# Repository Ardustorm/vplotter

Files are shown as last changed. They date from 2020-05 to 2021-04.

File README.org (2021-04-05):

* Intro
This project is a work in progress, but the goal is to make a hanging vplotter robot that is completely self contained and is controlled by the esp32. It uses 2 DC motors with encoders instead of the usual stepper motors.

I'm currently in the process of starting over again, this time using the Arduino framework since my goal is to make something that is easy for other people to use. (You can still checkout the previous version on its own branch.) Currently, I have remade a web debug interface using websockets that makes it easy to view, graph, and modify variables from a browser. I also was able to figure out how to read the encoders and update the motors from an ISR, and I'll be working on adding documentation about that shortly on hackaday.io. Eventually, I plan on splitting these parts of the code out into their own libraries since I think they could be useful for other people.

* Websockets debug
  https://hackaday.io/project/164975-portable-vertical-plotter/log/191201-websockets-debug

* This is built standing on the shoulders of these projects:
  - https://github.com/me-no-dev/AsyncTCP (esp32 webserver base)
  - https://github.com/me-no-dev/ESPAsyncWebServer (esp32 webserver with websockets)
  - https://picnicss.com/ (css styling for webpage)
  - https://github.com/leeoniya/uPlot/ (js plotting library)

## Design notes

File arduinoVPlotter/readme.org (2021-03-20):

* Overview
  - Right now I modified the sample script to be a simple websockets messaging app
  - I ran into a lot of issues, but the problem was me. I wasn't converting a 'String' into a char array which lead to a lot of issues.

* Notes:
  - Installed via zip:
    - https://github.com/me-no-dev/AsyncTCP
    - https://github.com/me-no-dev/ESPAsyncWebServer
  - Installed this to upload SPIFFS data:
    - https://github.com/me-no-dev/arduino-esp32fs-plugin
  - To use the built in js Ace editor navigate to url/edit

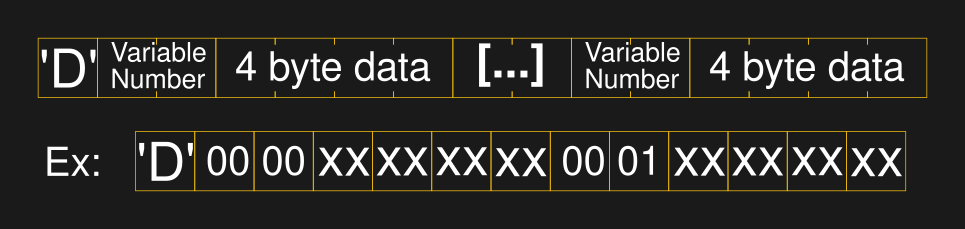
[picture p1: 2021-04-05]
documentation/websocketPackets_data.png

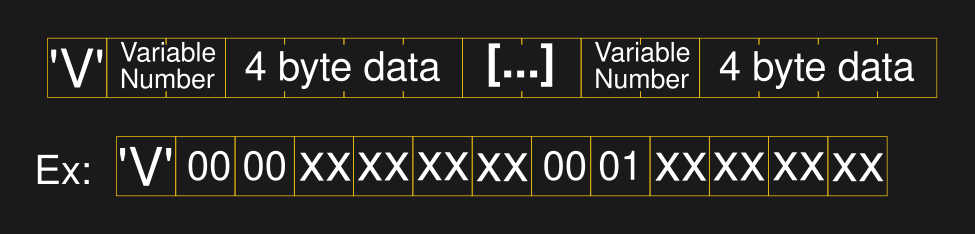
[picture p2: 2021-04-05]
documentation/websocketPackets_variable.png

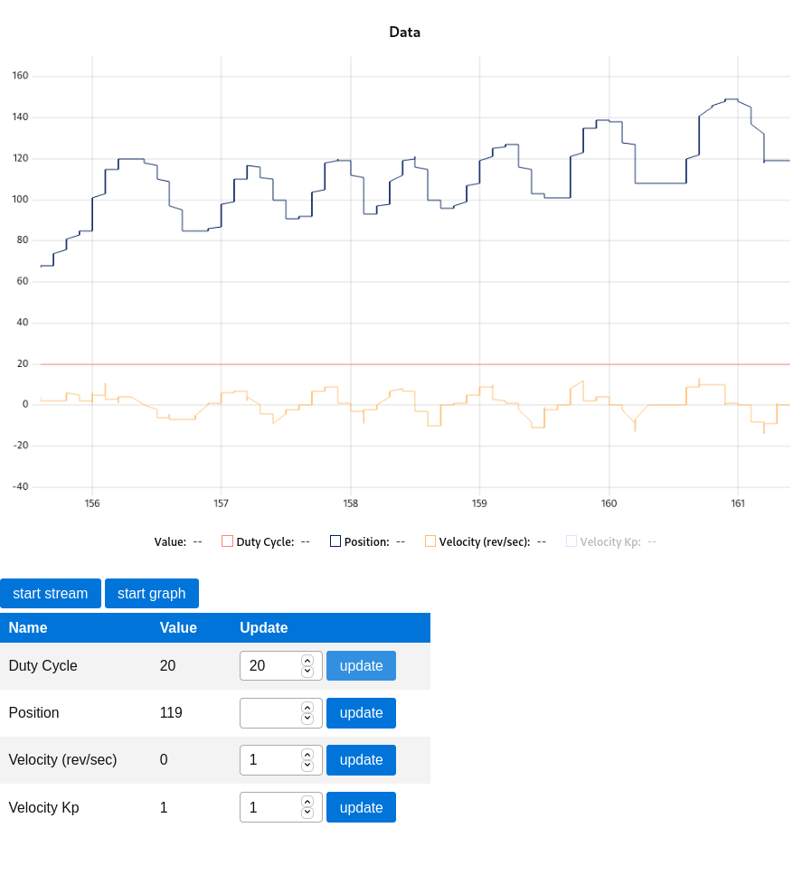
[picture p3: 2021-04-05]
documentation/websocketData_Screenshot.png

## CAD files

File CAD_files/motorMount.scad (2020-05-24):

$fn=100;
e=0.001;

dist = 70;

union(){
   translate([dist/2,0,0])
      motor();
   translate([-dist/2,0,0])
      motor();
   translate([0,0,1])
   cube([dist-10.5,15,2],center=true);
}



module motor(){
   wall = 1.5;
   depth = 10;
   translate([0,0,depth/2+wall/2])
   difference(){
      cube([10,12,depth]+[2*wall,2*wall,wall],center=true);
      translate([0,0,wall/2+e])
	 cube([10.25,12.25,depth],center=true);
      cylinder(d=4.5, h=4*depth, center=true);
   }
}

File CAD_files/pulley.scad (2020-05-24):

$fn=200;

diameter = 50;
lip_dia = 5;
lip_thick = 2;
width = 9;

pulley();

/* difference(){ */
/*    cylinder(d=15,h=5); */
/*    shaft(); */
/*    /\* lead-in's *\/ */
/*    translate([0,0,-0.1]) */
/*       cylinder(d1=4, d2=3,h=1.1); */

/*    } */

module pulley(){
   difference(){
      union(){
	 difference(){
	    union(){
	       cylinder(d=diameter, h=width);
	       cylinder(d=diameter+2*lip_dia, h=lip_thick);
	    }

	    cutouts();

	    /* lead-in's */
	    translate([0,0,width-1])
	       cylinder(d1=3, d2=4,h=1.1);
	    translate([0,0,-0.1])
	       cylinder(d1=4, d2=3,h=1.1);

	    /* Hole for thread */
	    translate([0,-diameter/3,width/2])rotate([90,0,0])
	       cylinder(r=.75,h=diameter);

	 }
	 cylinder(d=diameter/4, h=width);
      }
      shaft();
   }
}
module cutouts() {
   for(i=[0:60:360]) {
      rotate([0,0,i])hull(){
	 translate([0,diameter/8,0])
	    cylinder(d=diameter/10,h=width*3,center=true);
	 translate([0,diameter/3,0])
	    cylinder(d=diameter/3.5,h=width*3,center=true);
      }
   }
}

module shaft() {
   scale([1.05,1.05,1.05])
   intersection(){
      cylinder(d=3.2, h=width*3, center=true);
      translate([0,0.25,0])
	 cube([5,2.5,width*3],center=true);
	 }
}

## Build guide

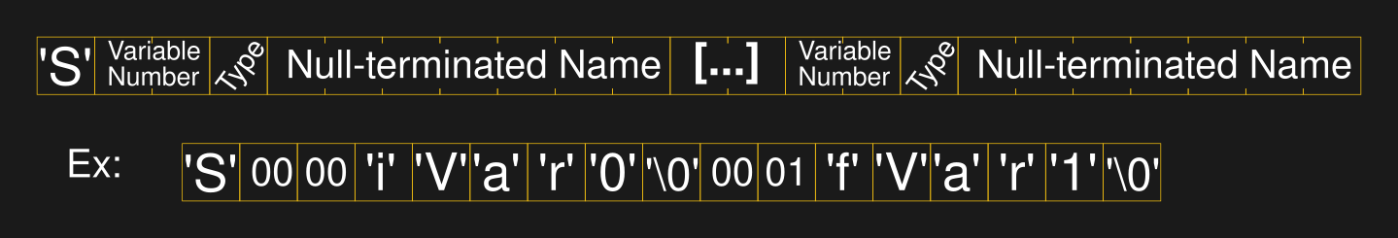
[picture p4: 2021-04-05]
documentation/websocketPackets_setup.png

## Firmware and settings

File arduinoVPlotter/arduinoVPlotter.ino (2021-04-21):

#include <ArduinoOTA.h>
#include <FS.h>
#include <SPIFFS.h>
#include <ESPmDNS.h>
#include <WiFi.h>
#include <AsyncTCP.h>
#include <ESPAsyncWebServer.h>
#include <SPIFFSEditor.h>

#include "wsData.h"
#include "motor.h"

WsData wsData;


float duty = 0;
float position = 0;
float velocityOut = 0;
float velocityKP = 0.1;

// SKETCH BEGIN
AsyncWebServer server(80);
AsyncWebSocket ws("/ws");

Motor motA = Motor(13, 12,      // motor
                   33, 32,      // encoder
                   200); // frequency


void onWsEvent(AsyncWebSocket * server, AsyncWebSocketClient * client, AwsEventType type, void * arg, uint8_t *data, size_t len){
    if(type == WS_EVT_DATA){
        AwsFrameInfo * info = (AwsFrameInfo*)arg;
        String msg = "";
        if(info->final && info->index == 0 && info->len == len){
            //the whole message is in a single frame and we got all of it's data
            if(info->opcode == WS_BINARY){
                wsData.processPacket(client, data, len);
            } else {
                Serial.printf("\nNon-Binary WS packet received\n ");
            }
        } else {
            Serial.printf("\nERR: WS data split in multiple frames! This functionality has been removed. "
                          "Either add it back in, or make frames smaller\n\n");
            // github.com/me-no-dev/ESPAsyncWebServer/blob/master/examples/ESP_AsyncFSBrowser/ESP_AsyncFSBrowser.ino#L35
        }
    }
}




// const char* ssid = "*******";
// const char* password = "*******";
#include "secrets.h"            //contains ssid and password, can use above instead
const char * hostName = "vplotter";
const char* http_username = "admin";
const char* http_password = "admin";

void setup(){
    Serial.begin(115200);
    Serial.setDebugOutput(true);
    WiFi.mode(WIFI_AP_STA);
    WiFi.softAP(hostName);
    WiFi.begin(ssid, password);
    if (WiFi.waitForConnectResult() != WL_CONNECTED) {
        Serial.printf("STA: Failed!\n");
        WiFi.disconnect(false);
        delay(1000);
        WiFi.begin(ssid, password);
    }

    ArduinoOTA.setHostname(hostName);
    ArduinoOTA.begin();

    MDNS.addService("http","tcp",80);

    SPIFFS.begin();

    ws.onEvent(onWsEvent);
    server.addHandler(&ws);



    // To access the editor go to url/edit
    server.addHandler(new SPIFFSEditor(SPIFFS, http_username,http_password));


    server.on("/heap", HTTP_GET, [](AsyncWebServerRequest *request){
            request->send(200, "text/plain", String(ESP.getFreeHeap()));
        });

    server.serveStatic("/", SPIFFS, "/").setDefaultFile("index.htm");

    server.onNotFound([](AsyncWebServerRequest *request){
            Serial.printf("NOT_FOUND: ");
            Serial.printf(" http://%s%s\n", request->host().c_str(), request->url().c_str());

            request->send(404);
        });
    server.onFileUpload([](AsyncWebServerRequest *request, const String& filename, size_t index, uint8_t *data, size_t len, bool final){
            if(!index)
                Serial.printf("UploadStart: %s\n", filename.c_str());
            Serial.printf("%s", (const char*)data);
            if(final)
                Serial.printf("UploadEnd: %s (%u)\n", filename.c_str(), index+len);
        });
    server.onRequestBody([](AsyncWebServerRequest *request, uint8_t *data, size_t len, size_t index, size_t total){
            if(!index)
                Serial.printf("BodyStart: %u\n", total);
            Serial.printf("%s", (const char*)data);
            if(index + len == total)
                Serial.printf("BodyEnd: %u\n", total);
        });
    server.begin();


    wsData.add(&duty, "Duty Cycle");
    wsData.add(&position, "Position");

    wsData.add(&velocityOut, "Velocity (rev/sec)");
    wsData.add(&velocityKP, "Velocity Kp");

}

void loop(){
    ArduinoOTA.handle();
    ws.cleanupClients();


    // motA.setDuty(duty);

    motA.setVelocity(duty);
    // motA.testControl(velocityKP);
    position = motA.getPosition();
    velocityOut = motA.getVelocity();
    // position = getPosition(0);
    // velocityOut = getVelocity(0);

}

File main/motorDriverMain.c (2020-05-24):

/* Pulse counter module - Example

   For other examples please check:
   https://github.com/espressif/esp-idf/tree/master/examples

   This example code is in the Public Domain (or CC0 licensed, at your option.)

   Unless required by applicable law or agreed to in writing, this
   software is distributed on an "AS IS" BASIS, WITHOUT WARRANTIES OR
   CONDITIONS OF ANY KIND, either express or implied.
*/
#include <stdio.h>
#include "freertos/FreeRTOS.h"
#include "freertos/portmacro.h"
#include "freertos/task.h"
#include "freertos/queue.h"
#include "driver/periph_ctrl.h"
#include "driver/mcpwm.h"
#include "driver/gpio.h"
#include "driver/pcnt.h"
#include "esp_attr.h"
#include "esp_log.h"
#include "soc/gpio_sig_map.h"
#include "soc/mcpwm_reg.h"
#include "soc/mcpwm_struct.h"


#include "wifi.h"
#include "motor.h"


void testDebug(void *arg);

void app_main()
{


   /* ######################### WIFI ################################# */
#ifdef CONFIG_ESPHTTPD_USE_ESPFS
      espFsInit((void*)(image_espfs_start));
      printf("\nUsing ESPFS\n");
#endif // CONFIG_ESPHTTPD_USE_ESPFS

      tcpip_adapter_init();
      httpdInit();
      init_wifi(false); // Supply false for STA mode
      esp_wifi_connect();
      /* xTaskCreate(websocketBcast, "wsbcast", 3000, NULL, 3, NULL); */

      printf("\nReady: %s\t%s\n", __DATE__, __TIME__);


      initMotors(motorPinOut);
      
    /* Motor */
    xTaskCreate(motorControl, "motorControl", 4096, NULL, 5, NULL);


    xTaskCreate(testDebug, "test_debug", 4096, NULL, 5, NULL);

    /* xTaskCreate(encoderEventsTask, "encodeEventsTask", 4096, NULL, 5, NULL); */

}


void testDebug(void *arg) {

   while(1) {
      printf("encoder0: %d \t encoder1: %d\n", encoderCount(PCNT_UNIT_0), encoderCount(PCNT_UNIT_1));
      vTaskDelay(1000/portTICK_RATE_MS);
   }

}

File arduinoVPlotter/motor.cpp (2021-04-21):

#include "motor.h"

// class for controling a motor using esp32 pcnt, mcpwm, and freeRTOS


// Used to keep track of what index to use for the pulse counter (pcnt) and motorController pwm unit (mcpwm)
int Motor::numberOfMotors = 0;
int Motor::velocityUpdateRate = 50000; // Period over which velocity is calculated in uS
int Motor::countsPerOutput = 24*115.5; // number of counts per desired unit (1 rotation, unit distance, etc.)

const int countsPerOutput = 24*115.5; // number of counts per desired unit (1 rotation, unit distance, etc.)

void saveMotor(int i, Motor* m);
void control_loop_task(void *param);


Motor::Motor(int motA, int motB, int encA, int encB, int pwmFreq) {
    int index = numberOfMotors++;
    pcnt_unit_t pcntUnit;
    mcpwm_unit_t mcpwmUnit;
    if(index == 0) {
        pcntUnit = PCNT_UNIT_0;
        mcpwmUnit = MCPWM_UNIT_0;
    } else if(index == 0) {
        pcntUnit = PCNT_UNIT_1;
        mcpwmUnit = MCPWM_UNIT_1;
    } else {
        // TODO: handle error
        printf("ERROR: MOTOR currently supports only 2 instances.\n");
        return;
    }
    saveMotor(index, this);
    pwmPeriod = 1e6 / pwmFreq;  // TODO: this might cause problems at higher frequencies
    // create configs
    configureEncoder(pcntUnit, encA, encB);
    configurePWM(mcpwmUnit, motA, motB, pwmFreq);

    if(index==0) {              // First motor configured
        // start control loop
        xTaskCreatePinnedToCore(control_loop_task, "control Loop", 4096, NULL, configMAX_PRIORITIES - 1, NULL, 1);
    }
}

void Motor::configureEncoder(pcnt_unit_t pcntUnit, int encA, int encB) {
    /* Prepare configuration for the PCNT unit */
    pcnt_config_t pcnt_config = {
        // Set PCNT input signal and control GPIOs
    pulse_gpio_num : encA,
    ctrl_gpio_num : encB,

    // What to do when control input is low or high?
    lctrl_mode : PCNT_MODE_KEEP, // Keep counting direction if low
    hctrl_mode : PCNT_MODE_REVERSE,    // reverse the primary counter mode if high

    // What to do on the positive / negative edge of pulse input?
    pos_mode : PCNT_COUNT_INC,   // Count up on the positive edge
    neg_mode : PCNT_COUNT_DEC,   // Count down on negative edge

    // Set the maximum and minimum limit values to watch
    counter_h_lim : PCNT_H_LIM_VAL,
    counter_l_lim : PCNT_L_LIM_VAL,

    unit : pcntUnit,
    channel : PCNT_CHANNEL_0,
    };

    /* Initialize PCNT unit */
    pcnt_unit_config(&pcnt_config);


    /* Use the second channel, switching the control and pulse pins and
       the direction to get full quadrature resolution*/
    pcnt_config.pulse_gpio_num = encB;
    pcnt_config.ctrl_gpio_num = encA;
    pcnt_config.channel = PCNT_CHANNEL_1;
    pcnt_config.pos_mode = PCNT_COUNT_DEC;   // Count down on the positive edge
    pcnt_config.neg_mode = PCNT_COUNT_INC;   // Count UP on negative edge


    /* Initialize PCNT unit with second channel configured */
    pcnt_unit_config(&pcnt_config);


    pcnt_event_enable(pcntUnit, PCNT_EVT_H_LIM);
    pcnt_event_enable(pcntUnit, PCNT_EVT_L_LIM);

    /* Initialize PCNT's counter */
    pcnt_counter_pause(pcntUnit);
    pcnt_counter_clear(pcntUnit);

    /* Register ISR handler and enable interrupts for PCNT unit */
    pcnt_isr_register(pcnt_example_intr_handler, NULL, 0, &user_isr_handle);
    pcnt_intr_enable(pcntUnit);

    /* Everything is set up, now go to counting */
    pcnt_counter_resume(pcntUnit);

}


void Motor::configurePWM(mcpwm_unit_t mcpwmUnit, int motA, int motB, int pwmFreq) {
    // Config MCPWM peripheral
    mcpwm_config_t pwm_config;
    pwm_config.frequency = pwmFreq;
    pwm_config.cmpr_a = 0;      // duty cycle of PWMxA = 0
    pwm_config.cmpr_b = 0;      // duty cycle of PWMxb = 0
    pwm_config.counter_mode = MCPWM_UP_COUNTER;
    pwm_config.duty_mode = MCPWM_DUTY_MODE_0;

    // Setup GPIO
    mcpwm_gpio_init(mcpwmUnit, MCPWM0A, motA);
    mcpwm_gpio_init(mcpwmUnit, MCPWM0B, motB);

    mcpwm_init(mcpwmUnit, MCPWM_TIMER_0, &pwm_config); // Configure PWM0A & PWM0B with above settings
}



/* Decode what PCNT's unit originated an interrupt
 * and updates the overflow array.
 * If you want to use the rest of the pcnt units for other things, you need to modify this function
 */
static void IRAM_ATTR pcnt_example_intr_handler(void *arg) {
    uint32_t intr_status = PCNT.int_st.val;
    int i;
    portBASE_TYPE HPTaskAwoken = pdFALSE;

    for (i = 0; i < PCNT_UNIT_MAX; i++) {
        if (intr_status & (BIT(i))) {

            PCNT.int_clr.val = BIT(i);
            if (PCNT.status_unit[i].val & PCNT_STATUS_L_LIM_M) {
                motorOverflow[i]--;
            }
            if (PCNT.status_unit[i].val & PCNT_STATUS_H_LIM_M) {
                motorOverflow[i]++;
            }

            if (HPTaskAwoken == pdTRUE) {
                portYIELD_FROM_ISR();
            }
        }
    }
}


/* Set duty cycle of the motor to a duty cycle cycle specified from -100 to +100) */
void Motor::setDuty(float duty_cycle) {
    if(duty_cycle >= 0) {        /* forward */
        mcpwm_set_signal_low(mcpwmNum, MCPWM_TIMER_0, MCPWM_OPR_B);
        mcpwm_set_duty(mcpwmNum, MCPWM_TIMER_0, MCPWM_OPR_A, duty_cycle);
        // call this each time, if operator was previously in low/high state
        mcpwm_set_duty_type(mcpwmNum, MCPWM_TIMER_0, MCPWM_OPR_A, MCPWM_DUTY_MODE_0);

    } else {                     /* backward */
        mcpwm_set_signal_low(mcpwmNum, MCPWM_TIMER_0, MCPWM_OPR_A);
        mcpwm_set_duty(mcpwmNum, MCPWM_TIMER_0, MCPWM_OPR_B, -1*duty_cycle);
        // call this each time, if operator was previously in low/high state
        mcpwm_set_duty_type(mcpwmNum, MCPWM_TIMER_0, MCPWM_OPR_B, MCPWM_DUTY_MODE_0);
    }
}

// Set velocity of motor
void Motor::setVelocity(float velocity) {
    // TODO: set mode to velocity
    velocitySetPoint = velocity * countsPerOutput * velocityUpdateRate/1e6;
    // targetVelocity[0] = velocity * countsPerOutput * velocityUpdateRate/1e6;
}

void Motor::testControl(float kp) {
    // velocity_KP[0] = kp;
    // setDuty((kp*(velocitySetPoint - velocity)));
}

float Motor::getPosition() {
    return  (float)position() / countsPerOutput;
}


/* Returns the encoder count for specified pulse counter,
   incorporating the over/underflow to get a 32 bit num*/
int32_t Motor::position() {
    int16_t count = 0;
    pcnt_get_counter_value((pcnt_unit_t)pcntUnit, &count);
    return (PCNT_H_LIM_VAL * motorOverflow[pcntUnit]) + count;
}
float Motor::getVelocity() {
    // return velocity[0];         // TODO fix
    return velocity * 1e6/velocityUpdateRate / countsPerOutput;
}

void Motor::controlLoop() {
    int32_t curPosition = position();
    velocity = curPosition - previousPosition;
    previousPosition = curPosition;
    setDuty(20 * (velocitySetPoint - getVelocity()));
 }


///////////////////////////////////////////////////////////
//////////////////// C style Functions ////////////////////
///////////////////////////////////////////////////////////
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

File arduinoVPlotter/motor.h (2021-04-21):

#ifndef __MOTOR_H__
#define __MOTOR_H__


// #include <stdio.h>
#include "freertos/FreeRTOS.h"
#include "freertos/task.h"
#include "driver/mcpwm.h"
#include "driver/pcnt.h"
#include "driver/timer.h"
#include "Arduino.h"

#define PCNT_H_LIM_VAL      ((int16_t) 0x7FFF)
#define PCNT_L_LIM_VAL      ((int16_t) 0x8000)



volatile static int32_t motorOverflow[8] = {0}; /* store over/underflow events for encoders */
static pcnt_isr_handle_t user_isr_handle = NULL; //user's ISR service handle
static void IRAM_ATTR pcnt_example_intr_handler(void *arg);



class Motor{
 public:
    Motor(int motA, int motB, int encA, int encB, int pwmFreq);
    void configureEncoder(pcnt_unit_t pcntUnit, int encA, int encB);
    void configurePWM(mcpwm_unit_t mcpwmUnit, int motA, int motB, int pwmFreq);
    void setDuty(float duty_cycle);     // from -100 to +100
    void setDuty_uS(int dutyPeriod);     // sets duty in uS
    void setVelocity(float velocity);
    float getPosition();                 // returns position in units (Revs)
    float getVelocity();                 // returns velocity in units (Revs/sec)
    void velocityControlLoop(uint32_t curTime);
    void testControl(float kp);         // Call control loop outside isr test

    void controlLoop();
    static int numberOfMotors;  // Indexes which pcnt/mcpwm to use (TODO: make private w/ getter method?)

 private:
    pcnt_unit_t pcntUnit;      // Which encoder this is using
    mcpwm_unit_t mcpwmNum;      // Which motor controller this is using
    uint32_t pwmPeriod;         // period in uS, used for setting duty in uS to avoid floats in isr

    int32_t position();                 // returns position in counts

    int32_t velocitySetPoint=0;             // stores target velocity in counts

    volatile int32_t velocity=0;             // stores current calculated velocity
    volatile int32_t previousPosition=0;     // Used for calculating velocity





    static int velocityUpdateRate; // Period over which velocity is calculated in uS
    static int countsPerOutput; // number of counts per desired unit (1 rotation, unit distance, etc.)


};

#endif /* __MOTOR_H__ */

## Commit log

2019-11-16 Adds esp32 code to control motor and read encoder (taken from esp-idf examples)
2019-11-16 combines example example websocket debug interface and motor controller code.
2019-11-16 moves most of the motor code into a seperate file
2019-11-16 simplifies interface for wsDebug, moves more code to motor.c, uses wsDebug for motor position
2019-11-17 adds ability for browser to query registered variablesand their values, it currently cannot set them
2020-01-31 Adds support for setting variables, displaying current value in graph, and the ability to send arbitrary packets via textbox for testing.
2020-02-01 adds basic proportional controller for motor that is controlable from the webpage.
2020-02-01 Starts restructuring the code to support multiple encoders and motors.
2020-02-01 Adds full quadrature support, doubling effective encoder resolution
2020-05-07 starts testing with 2 motors and encoders
2020-05-07 Starts working on physical parts of the design
    [motorMount.scad, pulley.scad]
2020-05-07 Refactored code to implement multiple motor inits
2020-05-08 Adds motor and encoder init function (using a struct) and starts brainstorming future structure of code.
2020-05-08 Cleans up motorControl function
2020-05-24 Adds primative ability to control both motors set points (and PID constants) from web interface
    [motorMount.scad, pulley.scad]
2020-05-25 Converts 'motor.c' and 'motorDriverMain.c' to C++ versions.
2021-03-20 Removes files unrelated to Arduino build.
2021-03-23 Removes a lot of the error handling and other functionality to reduce the code to only what is necessary to get system setup. Features can be added back later if needed.
    [arduinoVPlotter.ino]
2021-03-26 Adds variable type to setup packet and correctly interprets in js.
    [wsData.cpp]
2021-03-28 Adds Motor class for handling control of dc brushed motors with encoders. Most of the code was taken from the previous branch.
2021-03-28 Experiments with capturing velocity using timer interrupt.
2021-03-28 Report velocity in correct units.
    [arduinoVPlotter.ino, motor.cpp, motor.h]
2021-04-05 Updates readme to be more accurate, adds images, and cleans up some miscellaneous files that are no longer needed.
    [arduinoVPlotter.ino]
2021-04-08 Implements crude velocity control with feedforward and proportional control. Enables Floating point math in ISR. Rewrites some functions to be ISR/flash friendly.
2021-04-18 Implements esp-idf high resolution timers to call function for doing control. The task can be delayed, causing jitter greater than 1ms (or 15 ms when serving webpages).
    [arduinoVPlotter.ino]
2021-04-18 Implements control loop timing using a high priority task and a semaphore that is given in an ISR. Very low jitter (usually less than ~20 microseconds, though often higer when using SPIFFS).
    [arduinoVPlotter.ino]
2021-04-21 Refactors code so motor control loop is in motor class. Timer/alarm/isr doesn't work currently.
    [arduinoVPlotter.ino, motor.cpp, motor.h]
2021-04-21 Implements loop with callbacks, but still a lot of jitter.
    [arduinoVPlotter.ino, motor.cpp, motor.h]
2021-04-21 Makes original timer method work, very low jitter, but it is using the hal functions (which aren't very documented). Eventually this need to be replaced with the new api calls.
    [motor.cpp, motor.h]
